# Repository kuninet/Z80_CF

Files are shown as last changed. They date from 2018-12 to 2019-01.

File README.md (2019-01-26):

# Z80マイコン コンパクトフラッシュアダプタボード (KZ80-CF)

- SBC8080バスにつながるコンパクトフラッシュボード のデータ類です。
  - [128kB SRAMボード(KZ80-1MSRAM)](https://github.com/kuninet/Z80_1MRAMB)と組み合わせてCP/Mを動かす際に使用できます。
- 詳しい情報は以下のwikiページをご覧ください
  - https://github.com/kuninet/Z80_CF/wiki

## 回路図

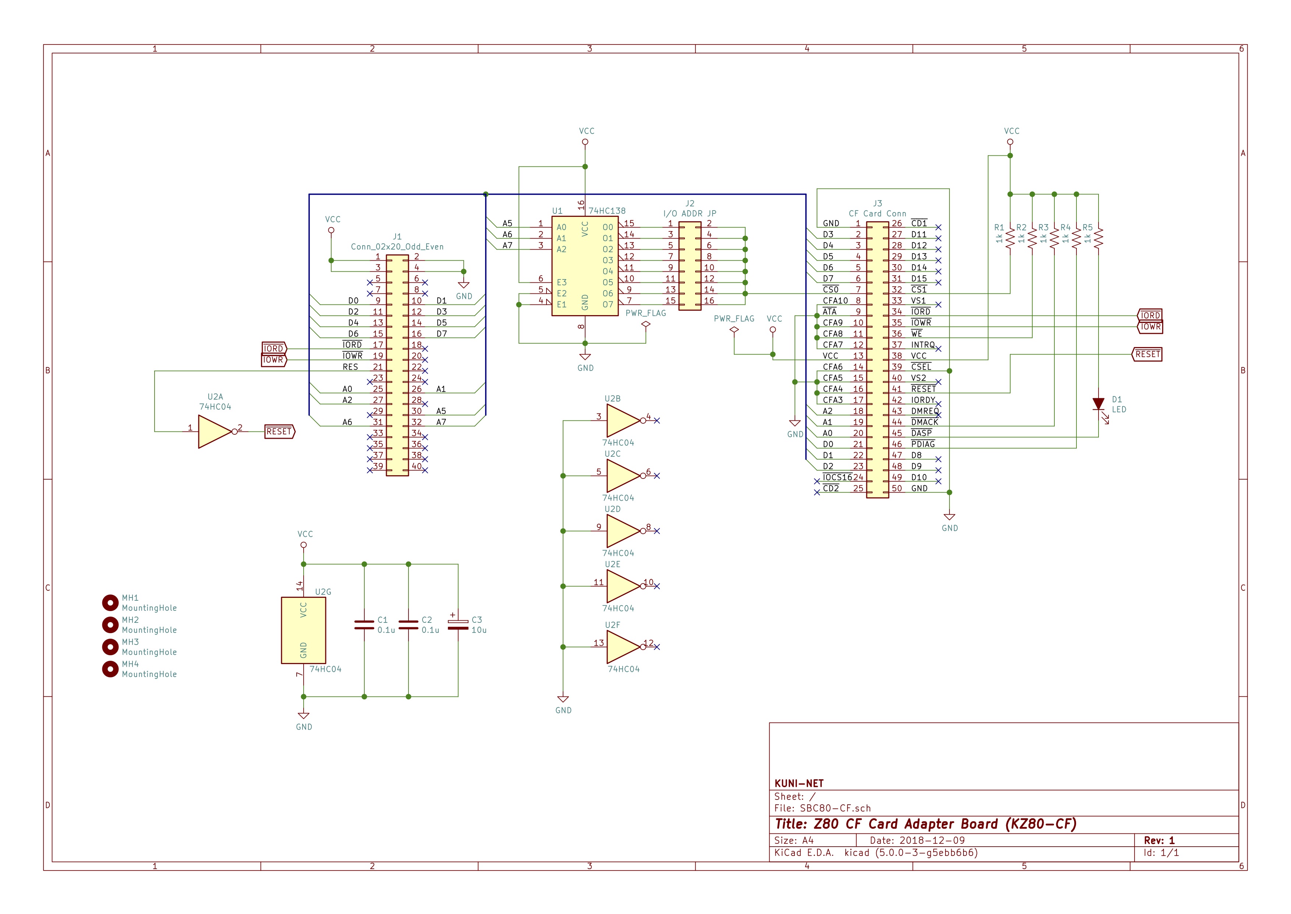
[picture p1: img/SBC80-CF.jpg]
回路図


[PDF版回路図はこちら](img/SBC80-CF.pdf)

## 部品表

- 部品表は以下にあります。OpenOffice等のcalcで開ける形式です
  - https://github.com/kuninet/Z80_CF/blob/master/KiCAD/SBC80-CF.ods

## 注意点

- REV1基板はコネクタのピンが誤って逆になっているため、CFカードの表裏を逆に挿入する必要があります。(ガイドのレールを削らないとうまくささりません) REV2では改善しています。
- CFカードコネクタは、REV1では秋月電子で手に入るネジ幅40mmのタイプを使用していますが、REV2ではマルツパーツ、aitendoで手に入るネジ幅38.78mmのタイプへ変更しています。

## ライセンス

- 本リポジトリのデータは MIT License のもとで公開します。

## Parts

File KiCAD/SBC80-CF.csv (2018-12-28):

Reference | Value | Footprint | Datasheet
J1 | Conn_02x20_Odd_Even | Connector_PinHeader_2.54mm:PinHeader_2x20_P2.54mm_Horizontal | ~
J3 | CF Card Conn | Connector:CF-50P | ~
D1 | LED | LED_THT:LED_D3.0mm | ~
U1 | 74HC138 | Package_DIP:DIP-16_W7.62mm_Socket | http://www.ti.com/lit/gpn/sn74LS138
J2 | I/O ADDR JP | Connector_PinHeader_2.54mm:PinHeader_2x08_P2.54mm_Vertical | ~
U2 | 74HC04 | Package_DIP:DIP-14_W7.62mm_Socket | http://www.nxp.com/documents/data_sheet/74HC_HCT04.pdf
C1 | 0.1u | Capacitor_THT:C_Disc_D5.0mm_W2.5mm_P5.00mm | ~
C2 | 0.1u | Capacitor_THT:C_Disc_D5.0mm_W2.5mm_P5.00mm | ~
C3 | 10u | Capacitor_THT:CP_Radial_D5.0mm_P2.50mm | ~
R1 | 1k | Resistor_THT:R_Axial_DIN0204_L3.6mm_D1.6mm_P7.62mm_Horizontal | ~
R2 | 1k | Resistor_THT:R_Axial_DIN0204_L3.6mm_D1.6mm_P7.62mm_Horizontal | ~
R3 | 1k | Resistor_THT:R_Axial_DIN0204_L3.6mm_D1.6mm_P7.62mm_Horizontal | ~
R4 | 1k | Resistor_THT:R_Axial_DIN0204_L3.6mm_D1.6mm_P7.62mm_Horizontal | ~
R5 | 1k | Resistor_THT:R_Axial_DIN0204_L3.6mm_D1.6mm_P7.62mm_Horizontal | ~
MH1 | MountingHole | MountingHole:MountingHole_3.2mm_M3 | ~
MH2 | MountingHole | MountingHole:MountingHole_3.2mm_M3 | ~
MH3 | MountingHole | MountingHole:MountingHole_3.2mm_M3 | ~
MH4 | MountingHole | MountingHole:MountingHole_3.2mm_M3 | ~

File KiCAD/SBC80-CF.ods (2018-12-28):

部品番号 | 仕様 | 数量 | 代替可能品 | Footprint
J1 | 40pinボックスヘッダ | 1 | 2列 ピンヘッダ | Connector_PinHeader_2.54mm:PinHeader_2x20_P2.54mm_Horizontal
J2 | 2列 2.5mmピンヘッダ 2x8 | 1 |  | Connector_PinHeader_2.54mm:PinHeader_2x08_P2.54mm_Vertical
J3 | GB-CFC-SLT | 1 | CF Card コネクター(マルツパーツ等) ネジ穴幅 38.78mm 部品面表記 CF-50P | Connector:CF-50P
D1 | LED | 1 | 3mm LED | LED_THT:LED_D3.0mm
U1 | 74HC138 | 1 | 74HCT138 | Package_DIP:DIP-16_W7.62mm_Socket
U2 | 74HC04 | 1 | 74HCT04 | Package_DIP:DIP-14_W7.62mm_Socket
C1、C2 | 0.1uF | 2 | 積層セラミックコンデンサ | Capacitor_THT:C_Disc_D5.0mm_W2.5mm_P5.00mm
C3 | 10uF | 1 | 電解コンデンサ | Capacitor_THT:CP_Radial_D5.0mm_P2.50mm
R1〜R5 | 1kΩ | 5 | 1/4W カーボン抵抗器 | Resistor_THT:R_Axial_DIN0204_L3.6mm_D1.6mm_P7.62mm_Horizontal

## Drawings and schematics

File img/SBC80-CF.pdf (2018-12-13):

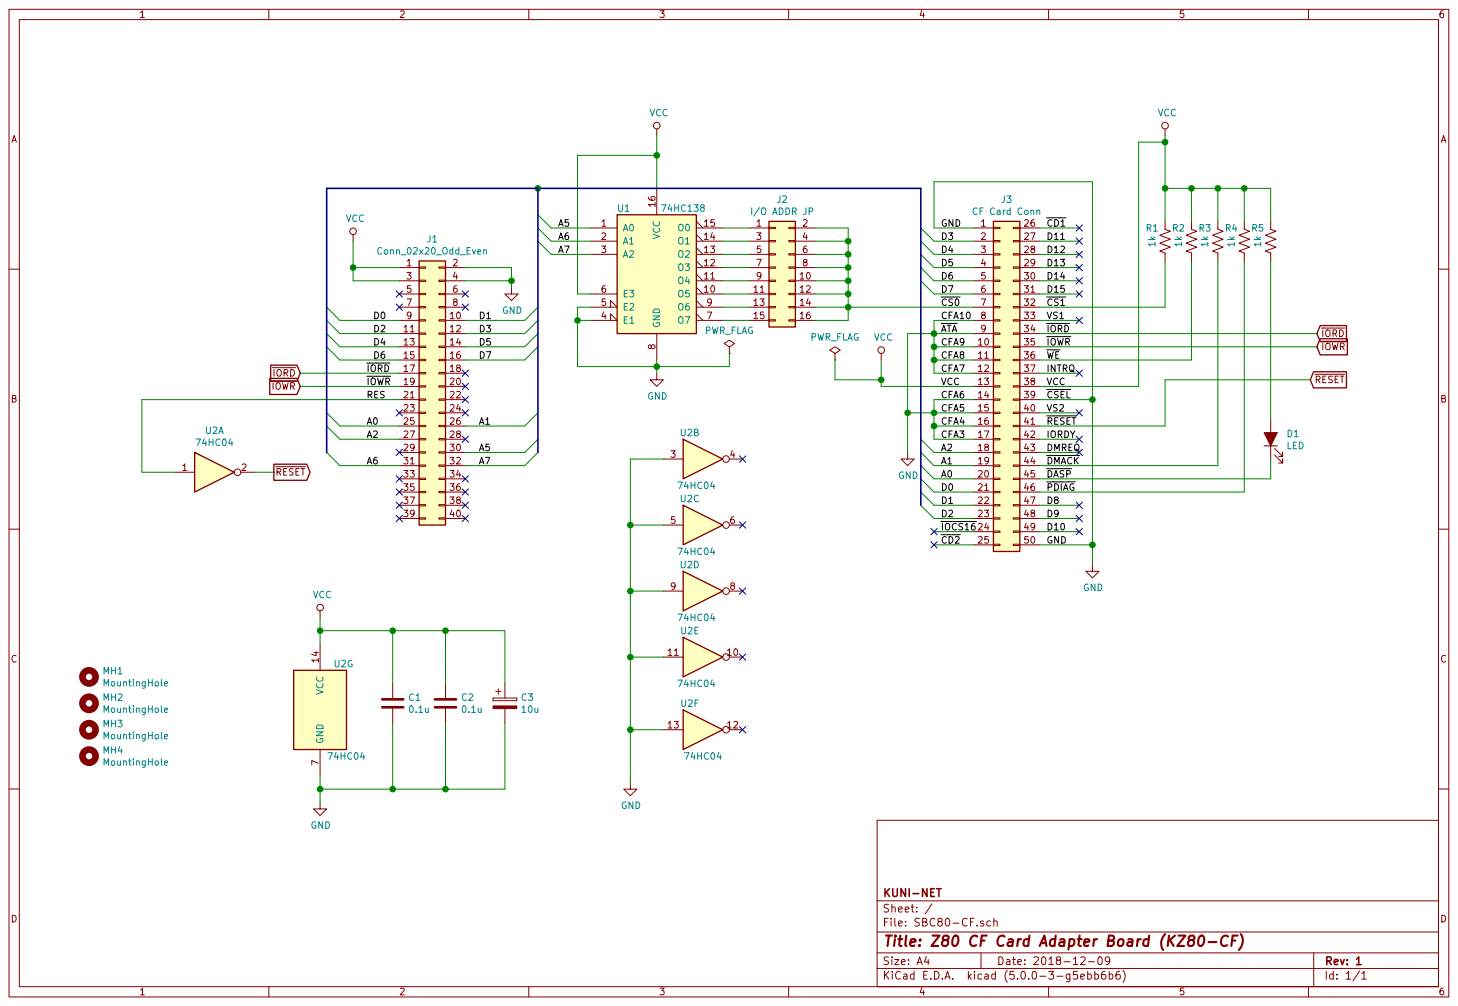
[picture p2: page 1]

VCC
J3 CF Card Conn D3 D4 D5 D6 D7 CS0 CFA10 ATA CFA9 CFA8 CFA7 VCC

15 | | CSEL VS2 RESET 40 41

MH1 MountingHole MH2 MountingHole MH3 MountingHole MH4 MountingHole

Id: 1/1 Title: Z80 CF Card Adapter Board (KZ80-CF) File: SBC80-CF.sch Sheet: / KUNI-NET

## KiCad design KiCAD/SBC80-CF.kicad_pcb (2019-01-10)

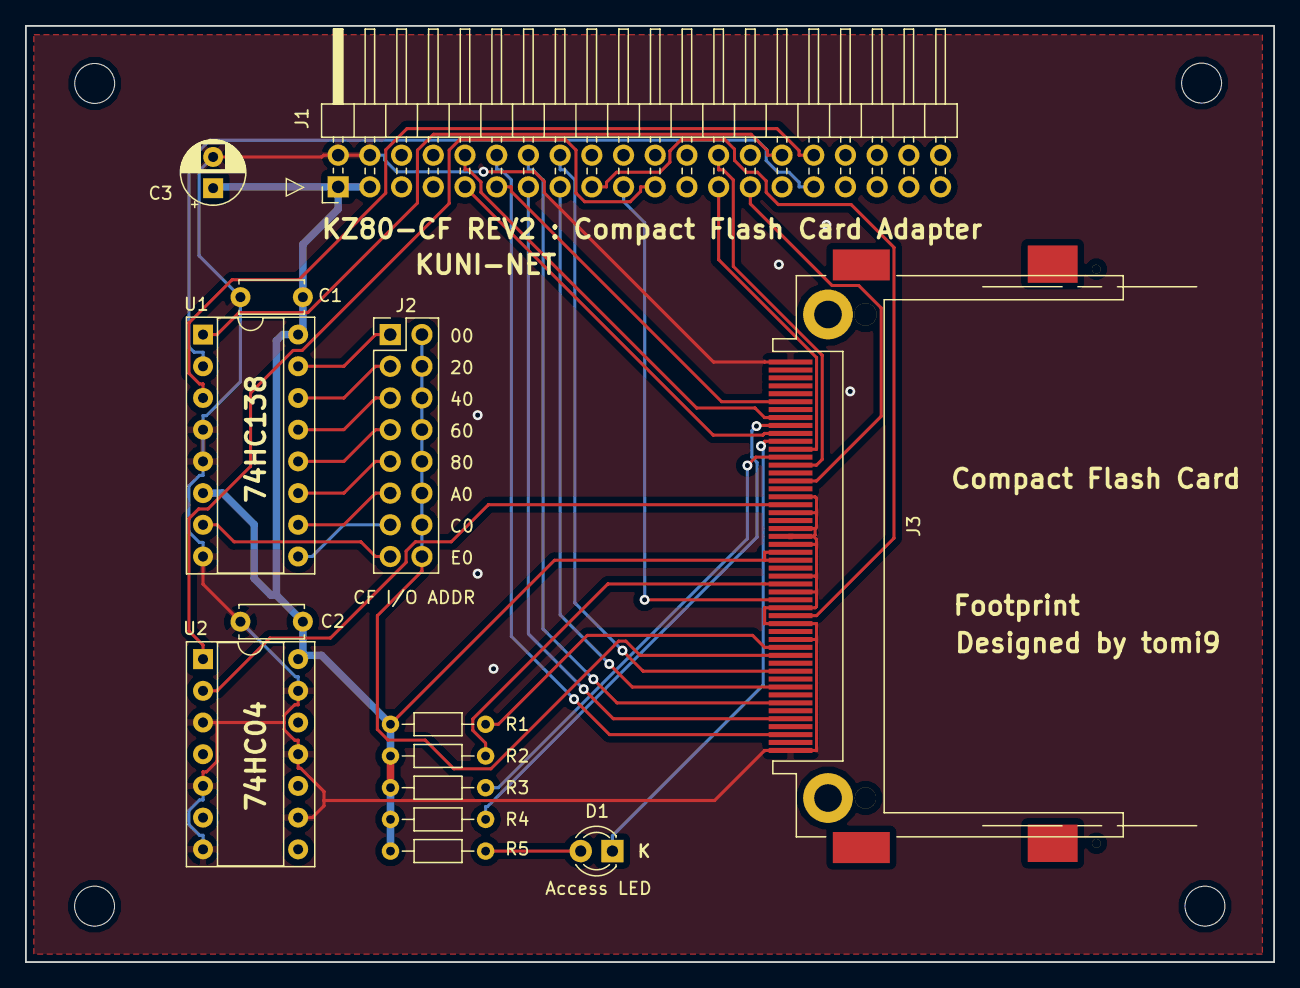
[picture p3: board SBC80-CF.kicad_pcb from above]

Board: 2 copper layers, 100.0 x 75.0 mm, 18 parts (0 on the bottom side), 35 nets.

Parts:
C1, C2: 0.1u; C_Disc_D5.0mm_W2.5mm_P5.00mm
C3: 10u; CP_Radial_D5.0mm_P2.50mm
D1: LED; LED_D3.0mm
J1: Conn_02x20_Odd_Even; PinHeader_2x20_P2.54mm_Horizontal
J2: I/O ADDR JP; PinHeader_2x08_P2.54mm_Vertical
J3: CF Card Conn; CF-50P
MH1, MH2, MH3, MH4: MountingHole; MountingHole_3.2mm_M3
R1, R2, R3, R4, R5: 1k; R_Axial_DIN0204_L3.6mm_D1.6mm_P7.62mm_Horizontal
U1: 74HC138; DIP-16_W7.62mm_Socket
U2: 74HC04; DIP-14_W7.62mm_Socket

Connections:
/A0: J1.25, J3.20
/A1: J1.26, J3.19
/A2: J1.27, J3.18
/A5: J1.30, U1.1
/A6: J1.31, U1.2
/A7: J1.32, U1.3
/D0: J1.9, J3.21
/D1: J1.10, J3.22
/D2: J1.11, J3.23
/D3: J1.12, J3.2
/D4: J1.13, J3.3
/D5: J1.14, J3.4
/D6: J1.15, J3.5
/D7: J1.16, J3.6
/RES: J1.21, U2.1
/~CS0: J2.2, J2.4, J2.6, J2.8, J2.10, J2.12, J2.14, J2.16, J3.7
/~CS1: J3.32, R1.2
/~DASP: D1.1, J3.45
/~DMACK: J3.44, R3.2
/~PDIAG: J3.46, R4.2
/~WE: J3.36, R2.2
GND: C1.2, C2.2, C3.2, J1.2, J1.4, J3.1, J3.8, J3.9, J3.10, J3.11, J3.12, J3.14, J3.15, J3.16, J3.17, J3.39, J3.50, U1.4, U1.5, U1.8, U2.3, U2.5, U2.7, U2.9, U2.11, U2.13
unnamed: D1.2, R5.2
unnamed: J2.1, U1.15
unnamed: J2.3, U1.14
unnamed: J2.5, U1.13
unnamed: J2.7, U1.12
unnamed: J2.9, U1.11
unnamed: J2.11, U1.10
unnamed: J2.13, U1.9
unnamed: J2.15, U1.7
VCC: C1.1, C2.1, C3.1, J1.1, J1.3, J3.13, J3.38, R1.1, R2.1, R3.1, R4.1, R5.1, U1.6, U1.16, U2.14
~IORD: J1.17, J3.34
~IOWR: J1.19, J3.35
~RESET: J3.41, U2.2

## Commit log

2018-12-13 init commit
    [SBC80-CF.dsn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]
2018-12-13 KiCADデータ・ディレクトリ移動
    [SBC80-CF.dsn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]
2018-12-13 README追加
2018-12-13 回路図等追加
2018-12-24 CFカード部品変更 REV2基板整備
    [SBC80-CF.dsn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]
2018-12-28 部品表整備
    [SBC80-CF.csv, SBC80-CF.ods]
2018-12-28 回路図リビジョン更新
    [SBC80-CF.sch]
2019-01-02 README追記
2019-01-10 シルクパターン等整備
    [SBC80-CF.kicad_pcb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]
